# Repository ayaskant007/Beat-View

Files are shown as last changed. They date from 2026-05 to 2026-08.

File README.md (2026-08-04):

# BEAT VIEW SPOTIFY DISPLAY

My very own desktop Spotify display + controller powered by a C3 MINI ESP32 and a ST77XX TFT LCD screen it has 3 mechanical switches to let me control the music playback directly
from my desk without constantly switching windows in my computer.

## Why This Project Was Made

I made this to solve the annyoance of always having to switch tabs/windows and interrupting my work just to skip a song or pause it, so i was just randomly one day decided to look into the stasis starter projects and i seemed to love the idea to built something to fix it so i made it.

## Project Media

[Click this to see the demo video](https://drive.google.com/file/d/1Z7YIdjlfjScMlj2ab83R-hnQqPh4U6T6/view?usp=sharing)





### 3D Model Render
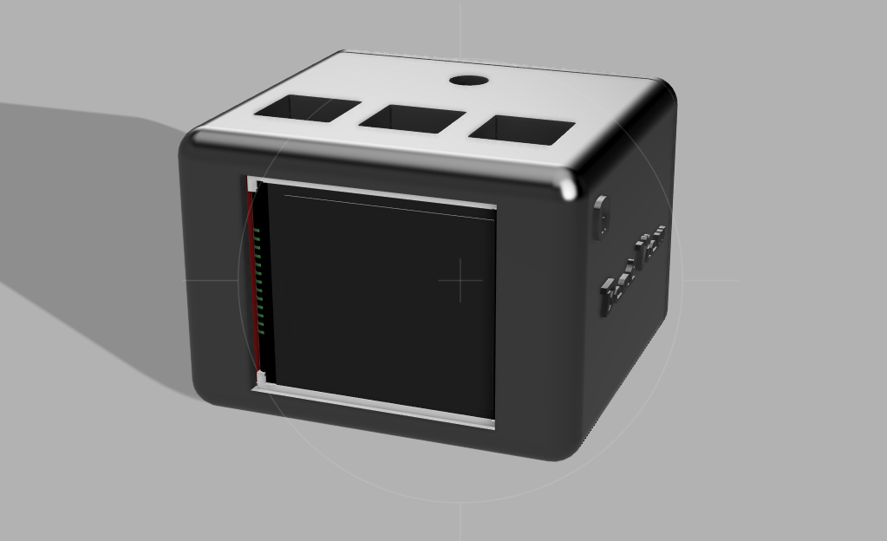
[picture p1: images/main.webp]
Fusion 360 3D Case Model



### PCB Layout
*Everything is handwired and doesnt use a PCB*

### Wiring Diagram
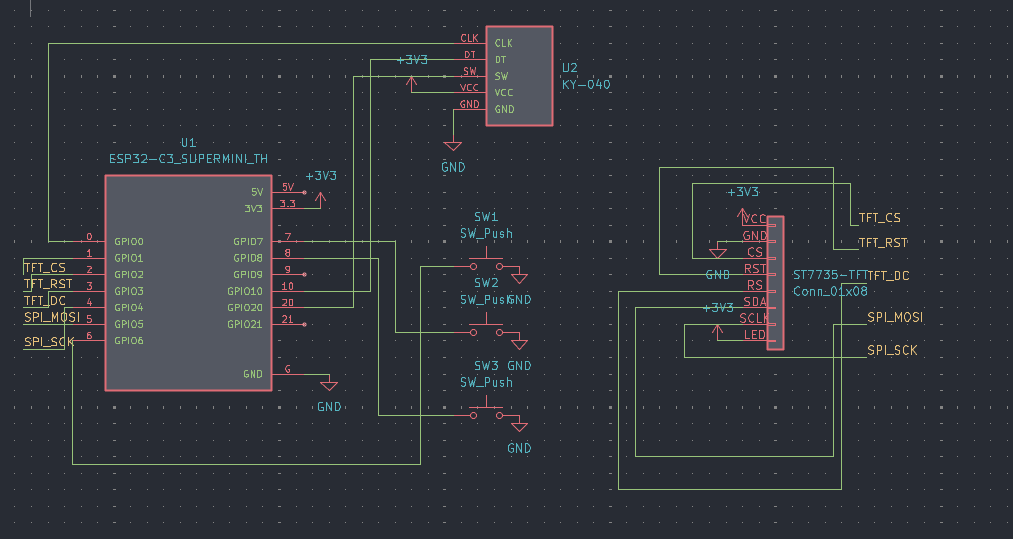
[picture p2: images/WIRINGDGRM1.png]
ESP32 C3 Mini to ST7735R Wiring Diagram


#### Reference Pin Map

| Physical Component | Component Pin Label | Wire to ESP32-C3 Mini Pin |
| --- | --- | --- |
| **1.8" TFT (ST7735R)** | **VCC** | **`3.3V`** |
|  | **GND** | **`GND`** |
|  | **CS** | **`2`** |
|  | **RESET / RST** | **`1`** |
|  | **DC / RS** | **`3`** |
|  | **SDA / MOSI** | **`6`** |
|  | **SCL / SCK** | **`4`** |
|  | **LED / BL** | **`3.3V`** |
| **HMX Xinhai Switches** | **Prev Switch Pin 1** | **`5`** | 
| *(Orientation doesn't* | **Play Switch Pin 1** | **`7`** | 
| *matter for switches)* | **Next Switch Pin 1** | **`TX` (GPIO 21)** | 
|  | **ALL Switch Pin 2s** | **`GND`** | 
| **Rotary Encoder** | **CLK (or A)** | **`0`** | 
|  | **DT (or B)** | **`10`** |  |
|  | **SW (Button Pin 1)** | **`RX` (GPIO 20)** | 
|  | **GND & Button Pin 2** | **`GND`** | 

---

## Bill of Materials (BOM)

| Name | Purpose | Qty | Total (USD) | Distributor | Link |
| :--- | :--- | :---: | :---: | :--- | :--- |
| **Rotary encoder module** | For volume control | 1 | $0.45 | Robocraze | https://robocraze.com/products/rotary-encoder-module?variant=40193048543385 |
| **Breadboard jumper wires** | For connecting the pin headers of the esp to the display and the key switches | 1 | $1.33 | Robocraze | [https://robocraze.com](https://robocraze.com/products/jumper-wire-set-m2m-m2f-f2f-40-pcs-each?variant=40192573636761) |
| **USB C data cable** | For connecting the display to my pc | 1 | $0.71 | Robocraze | [https://robocraze.com](https://robocraze.com/products/type-c-usb-cable-1-metre?variant=40193636303001) |
| **Keycaps** | For the keys for playing, pausing etc etc. | 1 | $1.04 | Meckeys | [https://meckeys.com](https://meckeys.com/shop/accessories/keyboard-accessories/keycaps/blank-dsa-keycaps-1u/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) |
| **Key switches** | For adding the play, pause functionality (HMX Xinhai 63.5g) | 1 | $3.38 | Meckeys | [https://meckeys.com](https://meckeys.com/shop/accessories/keyboard-accessories/keycaps/blank-dsa-keycaps-1u/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) |
| **1.8 inch TFT LCD module** | The display for actually showing the now playing status | 1 | $2.92 | Robocraze | [https://robocraze.com](https://robocraze.com/products/1-8-inch-tft-lcd-module) |
| **ESP32-C3 mini development board - unsoldered** | Main board for actually making the display work by fetching the data from spotify and also controlling what the display shows. | 1 | $2.65 | Robocraze | https://robocraze.com/products/esp32-c3-mini-development-board-unsoldered?variant=48465411506400 |
| **Sandpaper** | For sanding and smoothing the case for better adhesion. | 1 | $0 | Amazon | - |

---

### Additional Costs Summary

* **Tax (USD):** $1.37
* **Shipping (USD):** $1.56
* **Grand Total (USD):** $16.04

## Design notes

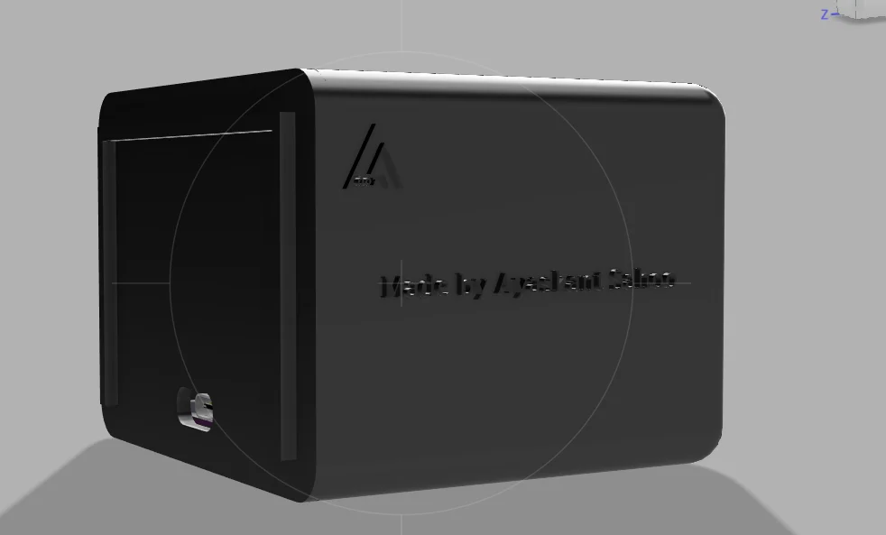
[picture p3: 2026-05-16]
images/1776142731075-7xjrsu.webp

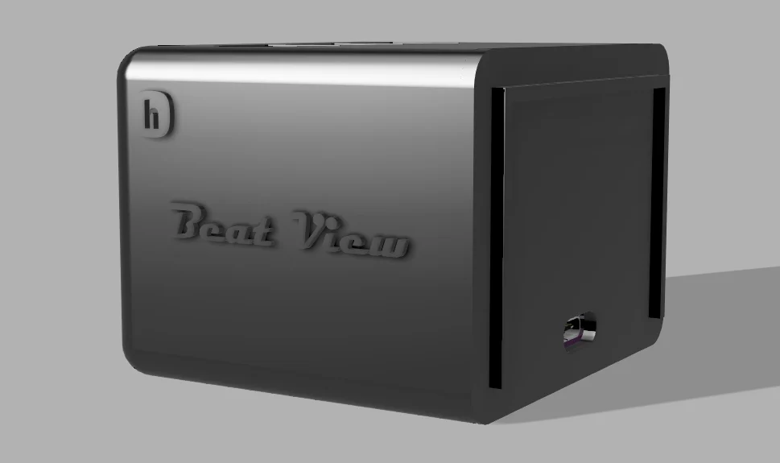
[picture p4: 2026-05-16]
images/1776142708711-ibmdzl.png

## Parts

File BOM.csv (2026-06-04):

Name | Purpose | Quantity | Total Cost (USD) | Link | Distributor
SANDPAPER | FOR SANDING AND SMOOTHING THE CASE FOR BETTER ADHESION | 1 | 0 | https://www.amazon.in/Premium-Automotive-Woodworking-Furniture-Finishing/dp/B0CCW36FQ1 | Amazon
Rotary Encoder Module | FOR VOLUME CONTROL | 1 | 0.45 | https://robocraze.com/products/rotary-encoder-module?variant=40193048543385 | ROBOCRAZE
Breadboard Jumper Wires | For connecting the pin headers of the ESP to the display and the key switches | 1 | 1.33 | https://robocraze.com/products/jumper-wire-set-m2m-m2f-f2f-40-pcs-each?variant=40192573636761 | ROBOCRAZE
USB C data cable | For connecting the display to my pc | 1 | 0.71 | https://robocraze.com/products/type-c-usb-cable-1-metre?variant=40193636303001 | Robocraze
Keycaps | For the keys for playing, pausing etc etc. | 1 | 1.04 | https://meckeys.com/shop/accessories/keyboard-accessories/keycaps/blank-dsa-keycaps-1u/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 | MECKEYS
Key Switches | For adding the play, pause functionality | 1 | 3.38 | https://meckeys.com/shop/accessories/keyboard-accessories/keycaps/blank-dsa-keycaps-1u/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 | MECKEYS
1.8 inch TFT LCD Module | The Display for actually showing the now playing status | 1 | 2.92 | https://robocraze.com/products/1-8-inch-tft-lcd-module | Robocraze
ESP32-C3 Mini Development Board - Unsoldered | Main board for actually making the display work by fetching the data from spotify and also controlling what the display shows. | 1 | 2.65 | https://robocraze.com/products/esp32-c3-mini-development-board-unsoldered?variant=48465411506400 | Robocraze
Tax (USD) |  |  | 1.37
Shipping (USD) |  |  | 1.56
 |  |  | 16.04

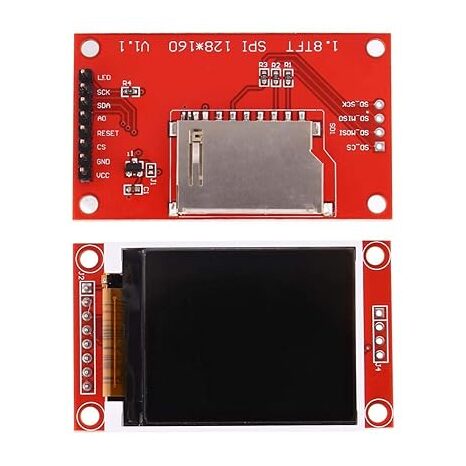
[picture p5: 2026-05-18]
Components/61HpxuwdU3L._SX466_-rotated.jpg

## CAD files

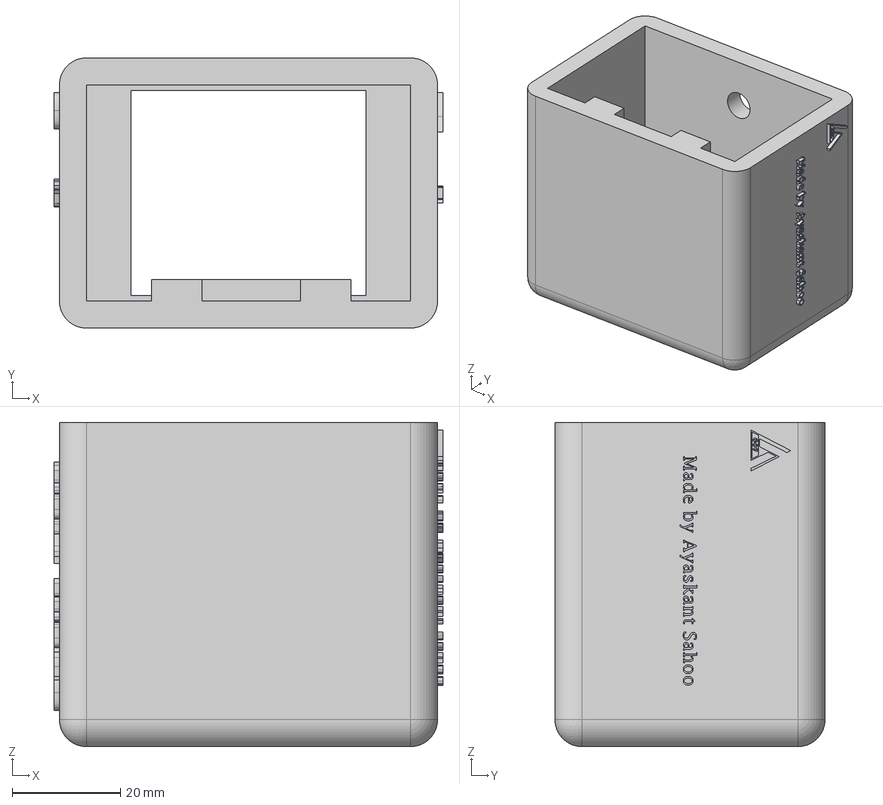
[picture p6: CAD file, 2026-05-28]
production/MainBody.step
72.0 x 50.0 x 60.0 mm

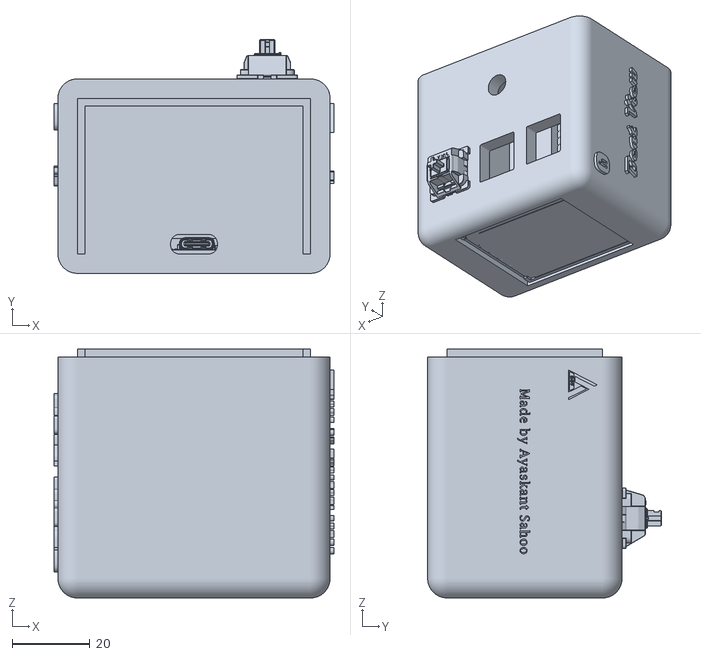
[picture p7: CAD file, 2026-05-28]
CAD/Beat View.stl
72.0 x 60.1 x 64.0

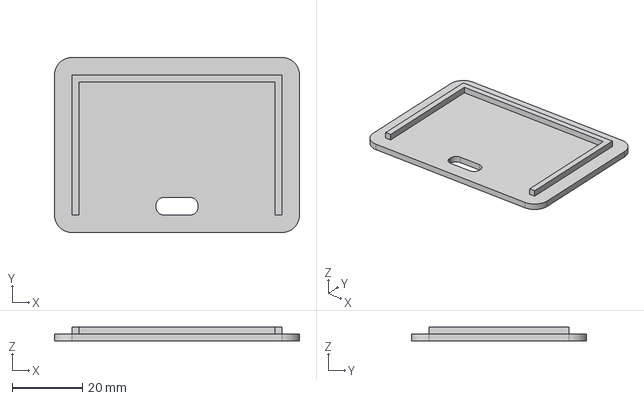
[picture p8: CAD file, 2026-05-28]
production/BackCover.step
70.0 x 50.0 x 4.00 mm

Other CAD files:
CAD/Beat View.f3z
production/BackCover.stl
production/MainBody.stl

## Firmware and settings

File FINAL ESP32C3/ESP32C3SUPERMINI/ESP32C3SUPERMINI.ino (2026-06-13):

#include <Arduino.h>
#include <Adafruit_GFX.h>
#include <Adafruit_ST7735.h>
#include <SPI.h>
#include <math.h>

// =====================================================
// ESP32-C3 SuperMini + ST7735 Media Controller
// Layout: 160x128 landscape
// =====================================================

// ------------------ TFT pins ------------------
#define TFT_CS    2
#define TFT_RST   1
#define TFT_DC    3
#define TFT_SCLK  4
#define TFT_MOSI  6

// ------------------ Controls ------------------
#define BTN_PREV  5
#define BTN_PLAY  7
#define BTN_NEXT  21
#define ENC_CLK   0
#define ENC_DT    10
#define ENC_SW    20

// ------------------ Display geometry ------------------
#define SW          160
#define SH          128

// Layout regions
#define HDR_H       12          // app name strip
#define FTR_H       20          // playback controls
#define BODY_Y      HDR_H
#define FTR_Y       (SH - FTR_H)
#define BODY_H      (FTR_Y - BODY_Y)   // 96px
// Title sub-canvas for proper clipping
#define TITLE_CV_W  (SW - TXT_X - 4)   // 84px wide
#define TITLE_CV_H  16

// Album art
#define ART_SIZE    60
#define ART_X       6
#define ART_Y       (BODY_Y + 4)

// Text area (right of album)
#define TXT_X       72
#define TXT_W       (SW - TXT_X - 4)
#define TITLE_Y     (BODY_Y + 6)
#define TITLE_H     14
#define ARTIST_Y    (BODY_Y + 24)
#define ARTIST_H    10
#define EQ_Y        (BODY_Y + 38)
#define EQ_H        18

// Progress bar (full width below album)
#define PROG_Y      (BODY_Y + 76)
#define PROG_TIME_Y (BODY_Y + 84)

// ------------------ Timing ------------------
#define D_BTN       45
#define D_CLK       3
#define D_SW        300
#define T_UI        40
#define T_VOL       1800
#define T_SCROLL    50
#define SCROLL_GAP  30
#define SCROLL_PAUSE 1000

// ------------------ Colors (RGB565) ------------------
#define C_BG        0x0000
#define C_PANEL     0x18E3
#define C_PANEL_2   0x2965
#define C_TEXT      0xFFFF
#define C_MUTED     0xACD3
#define C_DIM       0x6B4D
#define C_ACCENT    0x07FF
#define C_DANGER    0xF800

Adafruit_ST7735 tft(TFT_CS, TFT_DC, TFT_RST);
GFXcanvas16 bodyCanvas(SW, BODY_H);
GFXcanvas16 footerCanvas(SW, FTR_H);
GFXcanvas16 headerCanvas(SW, HDR_H);
GFXcanvas16 titleCanvas(TITLE_CV_W, TITLE_CV_H);

// ------------------ State ------------------
struct Track {
  String artist = "";
  String name = "";
  String app = "";
  bool playing = false;
  int progress = 0;
  int duration = 0;
};

Track cur;
int vol = 50;
bool shuf = false;
bool muted = false;

// Inputs
int lastClk = HIGH;
bool lastSw = HIGH;
bool lastBtnState[3] = {HIGH, HIGH, HIGH};
unsigned long tBtn[3] = {0, 0, 0};
unsigned long tClk = 0;
unsigned long tSw = 0;
unsigned long tUi = 0;
unsigned long tScroll = 0;
unsigned long tVol = 0;
unsigned long tScrollPause = 0;

bool volVisible = false;
bool scrolling = false;
int scrollX = 0;
int textW = 0;
uint32_t frameId = 0;

// EQ bars (8 bars)
#define EQ_BARS 8
float eqH[EQ_BARS]      = {3, 6, 9, 4, 7, 5, 8, 3};
float targetEq[EQ_BARS] = {3, 6, 9, 4, 7, 5, 8, 3};

String rxLine;

// Album art
uint16_t albumArt[ART_SIZE * ART_SIZE];
bool artReady = false;
bool artReceiving = false;
bool artAwaitTerm = false;
int artExpected = 0;
int artIndex = 0;
int artW = ART_SIZE;
int artH = ART_SIZE;

// Theme color from PC (extracted from album art)
uint16_t themeColor = C_ACCENT;
uint8_t themeR = 0, themeG = 200, themeB = 255;

// Visual pulse for play indicator
float pulsePhase = 0;

// ------------------ Helpers ------------------
static bool valid(const String& s) {
  return s.length() > 0 && s != "null" && s != "error";
}

static String safeText(String s, int maxLen = 60) {
  s.replace("\r", " ");
  s.replace("\n", " ");
  s.replace("|", "/");
  s.trim();
  if ((int)s.length() > maxLen) s = s.substring(0, maxLen);
  return s;
}

static String formatTime(int ms) {
  if (ms < 0) ms = 0;
  int total = ms / 1000;
  int m = total / 60;
  int s = total % 60;
  char buf[10];
  snprintf(buf, sizeof(buf), "%d:%02d", m, s);
  return String(buf);
}

static uint16_t rgb565(uint8_t r, uint8_t g, uint8_t b) {
  return ((r & 0xF8) << 8) | ((g & 0xFC) << 3) | (b >> 3);
}

static uint16_t blend565(uint16_t a, uint16_t b, uint8_t t) {
  uint8_t ar = (a >> 11) & 0x1F, ag = (a >> 5) & 0x3F, ab = a & 0x1F;
  uint8_t br = (b >> 11) & 0x1F, bg = (b >> 5) & 0x3F, bb = b & 0x1F;
  uint8_t rr = ar + (((int)br - ar) * t >> 8);
  uint8_t gg = ag + (((int)bg - ag) * t >> 8);
  uint8_t bb2 = ab + (((int)bb - ab) * t >> 8);
  return (rr << 11) | (gg << 5) | bb2;
}

static uint16_t darken(uint16_t c, uint8_t amt) {
  return blend565(c, C_BG, amt);
}

static uint16_t lighten(uint16_t c, uint8_t amt) {
  return blend565(c, C_TEXT, amt);
}

static String initialsFromTitle(const String& s) {
  String out;
  bool take = true;
  for (unsigned i = 0; i < s.length() && out.length() < 2; i++) {
    char c = s[i];
    if (isalnum((unsigned char)c)) {
      if (take) { out += (char)toupper(c); take = false; }
    } else take = true;
  }
  if (out.length() == 0) out = "?";
  return out;
}

// ------------------ Drawing primitives ------------------

// Vertical gradient fill on canvas
static void fillGradV(GFXcanvas16& c, int x, int y, int w, int h, uint16_t top, uint16_t bot) {
  for (int i = 0; i < h; i++) {
    uint8_t t = (h > 1) ? (uint8_t)((i * 255L) / (h - 1)) : 0;
    c.drawFastHLine(x, y + i, w, blend565(top, bot, t));
  }
}

// Draw album art with rounded corners and subtle border
static void drawAlbumArt(GFXcanvas16& c) {
  int ay = ART_Y - BODY_Y;  // translate to canvas-local Y
  
  if (artReady && artW == ART_SIZE && artH == ART_SIZE) {
    c.drawRGBBitmap(ART_X, ay, albumArt, ART_SIZE, ART_SIZE);
  } else {
    // Fallback: gradient square with initials
    uint16_t topC = lighten(themeColor, 40);
    uint16_t botC = darken(themeColor, 60);
    fillGradV(c, ART_X, ay, ART_SIZE, ART_SIZE, topC, botC);
    
    // Decorative circle
    c.drawCircle(ART_X + ART_SIZE/2, ay + ART_SIZE/2, 18, lighten(themeColor, 80));
    c.drawCircle(ART_X + ART_SIZE/2, ay + ART_SIZE/2, 14, lighten(themeColor, 120));
    
    String init = initialsFromTitle(valid(cur.name) ? cur.name : "?");
    c.setTextSize(3);
    c.setTextColor(C_TEXT);
    int16_t x1, y1; uint16_t tw, th;
    c.getTextBounds(init, 0, 0, &x1, &y1, &tw, &th);
    c.setCursor(ART_X + (ART_SIZE - tw)/2, ay + (ART_SIZE - th)/2);
    c.print(init);
  }
  
  // Border
  c.drawRect(ART_X - 1, ay - 1, ART_SIZE + 2, ART_SIZE + 2, darken(themeColor, 100));
  c.drawRect(ART_X, ay, ART_SIZE, ART_SIZE, themeColor);
}

// Animated EQ bars
static void drawEqBars(GFXcanvas16& c) {
  int ey = EQ_Y - BODY_Y;
  int barW = 3;
  int gap = 2;
  int totalW = EQ_BARS * (barW + gap) - gap;
  int startX = TXT_X;
  
  for (int i = 0; i < EQ_BARS; i++) {
    int bx = startX + i * (barW + gap);
    
    // Background slot
    c.fillRect(bx, ey, barW, EQ_H, C_PANEL);
    
    if (cur.playing) {
      // Animate toward target
      if (abs(eqH[i] - targetEq[i]) < 0.5f) {
        targetEq[i] = random(2, EQ_H + 1);
      }
      eqH[i] += (targetEq[i] - eqH[i]) * 0.35f;
      
      int h = (int)eqH[i];
      if (h < 2) h = 2;
      
      // Gradient bar
      for (int j = 0; j < h; j++) {
        uint8_t t = (uint8_t)((j * 255L) / EQ_H);
        uint16_t col = blend565(themeColor, lighten(themeColor, 120), t);
        c.drawFastHLine(bx, ey + EQ_H - h + j, barW, col);
      }
    } else {
      // Paused: flat low bar
      eqH[i] = 2;
      c.fillRect(bx, ey + EQ_H - 2, barW, 2, C_DIM);
    }
  }
}

// Progress bar
static void drawProgress(GFXcanvas16& c) {
  int py = PROG_Y - BODY_Y;
  int pad = 6;
  int barW = SW - pad * 2;
  int barH = 4;
  
  // Background track
  c.fillRoundRect(pad, py, barW, barH, 2, C_PANEL);
  
  int pct = (cur.duration > 0) ? 
            map(constrain(cur.progress, 0, cur.duration), 0, cur.duration, 0, barW) : 0;
  
  if (pct > 0) {
    // Gradient fill
    for (int i = 0; i < pct; i++) {
      uint8_t t = (uint8_t)((i * 255L) / barW);
      uint16_t col = blend565(darken(themeColor, 40), lighten(themeColor, 60), t);
      c.drawFastVLine(pad + i, py, barH, col);
    }
    // Playhead dot
    int dotX = pad + pct;
    if (dotX < pad + barW) {
      c.fillCircle(dotX, py + barH/2, 3, C_TEXT);
      c.drawCircle(dotX, py + barH/2, 3, themeColor);
    }
  }
  
  // Time labels
  int ty = PROG_TIME_Y - BODY_Y;
  c.setTextSize(1);
  c.setTextColor(C_MUTED);
  c.setCursor(pad, ty);
  c.print(formatTime(cur.progress));
  
  String rt = formatTime(cur.duration);
  int16_t x1, y1; uint16_t tw, th;
  c.getTextBounds(rt, 0, 0, &x1, &y1, &tw, &th);
  c.setCursor(SW - pad - tw, ty);
  c.print(rt);
}

// Scrolling title text
static void drawTitle(GFXcanvas16& c) {
  String title = valid(cur.name) ? cur.name : "No track playing";
  title = safeText(title, 80);
  
  // Render onto title sub-canvas (hard-clipped region)
  titleCanvas.fillScreen(C_BG);
  // Match body gradient at title row so it blends
  uint16_t bgTop = darken(themeColor, 220);
  uint16_t bgBot = C_BG;
  int rowY = TITLE_Y - BODY_Y;
  for (int i = 0; i < TITLE_CV_H; i++) {
    int absY = rowY + i;
    uint8_t t = (BODY_H > 1) ? (uint8_t)((absY * 255L) / (BODY_H - 1)) : 0;
    titleCanvas.drawFastHLine(0, i, TITLE_CV_W, blend565(bgTop, bgBot, t));
  }
  
  titleCanvas.setTextSize(2);
  titleCanvas.setTextColor(C_TEXT);
  titleCanvas.setTextWrap(false);
  
  int16_t x1, y1; uint16_t tw, th;
  titleCanvas.getTextBounds(title, 0, 0, &x1, &y1, &tw, &th);
  textW = tw;
  
  if (textW > TITLE_CV_W) {
    scrolling = true;
    titleCanvas.setCursor(scrollX, 1);
    titleCanvas.print(title);
    
    int secondX = scrollX + textW + SCROLL_GAP;
    if (secondX < TITLE_CV_W) {
      titleCanvas.setCursor(secondX, 1);
      titleCanvas.print(title);
    }
  } else {
    scrolling = false;
    scrollX = 0;
    titleCanvas.setCursor(0, 1);
    titleCanvas.print(title);
  }
  
  // Blit title canvas onto body canvas - pixels outside TITLE_CV_W are physically gone
  c.drawRGBBitmap(TXT_X, rowY, titleCanvas.getBuffer(), TITLE_CV_W, TITLE_CV_H);
}

// Artist line
static void drawArtist(GFXcanvas16& c) {
  String artist = valid(cur.artist) ? cur.artist : "Open music on Windows";
  artist = safeText(artist, 30);
  
  c.setTextSize(1);
  c.setTextColor(lighten(themeColor, 80));
  
  // Truncate with ellipsis if too long
  int16_t x1, y1; uint16_t tw, th;
  c.getTextBounds(artist, 0, 0, &x1, &y1, &tw, &th);
  while ((int)tw > TXT_W && artist.length() > 4) {
    artist = artist.substring(0, artist.length() - 2);
    c.getTextBounds(artist + "..", 0, 0, &x1, &y1, &tw, &th);
  }
  if (tw > TXT_W - 12) artist = artist.substring(0, artist.length() - 2) + "..";
  
  c.setCursor(TXT_X, ARTIST_Y - BODY_Y);
  c.print(artist);
}

// Volume popup overlay
static void drawVolumePopup(GFXcanvas16& c) {
  int pw = 130;
  int ph = 32;
  int px = (SW - pw) / 2;
  int py = (BODY_H - ph) / 2;
  
  // Shadow
  c.fillRoundRect(px + 2, py + 2, pw, ph, 6, C_BG);
  // Panel
  c.fillRoundRect(px, py, pw, ph, 6, C_PANEL_2);
  c.drawRoundRect(px, py, pw, ph, 6, themeColor);
  
  // Speaker icon (simple)
  int ix = px + 8;
  int iy = py + ph/2;
  c.fillTriangle(ix, iy - 4, ix + 6, iy - 6, ix + 6, iy + 6, C_TEXT);
  c.fillTriangle(ix, iy + 4, ix + 6, iy + 6, ix + 6, iy - 6, C_TEXT);
  if (vol > 30 && !muted) c.drawCircle(ix + 10, iy, 4, C_TEXT);
  if (vol > 70 && !muted) c.drawCircle(ix + 10, iy, 7, C_TEXT);
  if (muted) {
    c.drawLine(ix, iy - 6, ix + 14, iy + 6, C_DANGER);
    c.drawLine(ix, iy + 6, ix + 14, iy - 6, C_DANGER);
  }
  
  // Bar
  int barX = px + 28;
  int barY = py + ph/2 - 3;
  int barW = pw - 60;
  c.fillRoundRect(barX, barY, barW, 6, 3, C_BG);
  int fill = map(constrain(vol, 0, 100), 0, 100, 0, barW);
  if (fill > 0) {
    for (int i = 0; i < fill; i++) {
      uint8_t t = (uint8_t)((i * 255L) / barW);
      c.drawFastVLine(barX + i, barY, 6, blend565(themeColor, lighten(themeColor, 100), t));
    }
  }
  
  // Percent
  c.setTextSize(1);
  c.setTextColor(C_TEXT);
  char buf[8];
  snprintf(buf, sizeof(buf), "%d%%", vol);
  int16_t x1, y1; uint16_t tw, th;
  c.getTextBounds(buf, 0, 0, &x1, &y1, &tw, &th);
  c.setCursor(px + pw - tw - 8, py + ph/2 - 3);
  c.print(buf);
}

// ------------------ Region draw functions ------------------

static void drawHeader() {
  headerCanvas.fillScreen(C_BG);
  fillGradV(headerCanvas, 0, 0, SW, HDR_H, darken(themeColor, 180), C_BG);
  
  headerCanvas.setTextSize(1);
  headerCanvas.setTextColor(lighten(themeColor, 60));
  headerCanvas.setCursor(4, 2);
  headerCanvas.print("NOW PLAYING");
  
  // App badge on right
  String app = valid(cur.app) ? safeText(cur.app, 12) : String("---");
  app.toUpperCase();
  int16_t x1, y1; uint16_t tw, th;
  headerCanvas.getTextBounds(app, 0, 0, &x1, &y1, &tw, &th);
  headerCanvas.setTextColor(C_MUTED);
  headerCanvas.setCursor(SW - tw - 4, 2);
  headerCanvas.print(app);
  
  // Status dot
  uint16_t dotC = valid(cur.name) ? (cur.playing ? themeColor : C_DIM) : C_DANGER;
  headerCanvas.fillCircle(SW - tw - 12, 5, 2, dotC);
  
  tft.drawRGBBitmap(0, 0, headerCanvas.getBuffer(), SW, HDR_H);
}

static void drawBody() {
  // Background gradient using theme color
  uint16_t bgTop = darken(themeColor, 220);
  uint16_t bgBot = C_BG;
  fillGradV(bodyCanvas, 0, 0, SW, BODY_H, bgTop, bgBot);
  
  drawAlbumArt(bodyCanvas);
  drawTitle(bodyCanvas);
  drawArtist(bodyCanvas);
  drawEqBars(bodyCanvas);
  drawProgress(bodyCanvas);
  
  if (volVisible) {
    drawVolumePopup(bodyCanvas);
  }
  
  tft.drawRGBBitmap(0, BODY_Y, bodyCanvas.getBuffer(), SW, BODY_H);
}

static void drawFooter() {
  footerCanvas.fillScreen(C_BG);
  fillGradV(footerCanvas, 0, 0, SW, FTR_H, C_BG, darken(themeColor, 200));
  
  // Top separator
  footerCanvas.drawFastHLine(0, 0, SW, darken(themeColor, 100));
  
  int cy = FTR_H / 2;
  
  // Prev button
  int px1 = 28;
  footerCanvas.fillCircle(px1, cy, 8, C_PANEL);
  // Draw prev triangle
  footerCanvas.fillTriangle(px1 + 2, cy - 4, px1 + 2, cy + 4, px1 - 3, cy, C_TEXT);
  footerCanvas.fillRect(px1 - 4, cy - 4, 2, 9, C_TEXT);
  
  // Play/Pause button (center, bigger)
  int px2 = SW / 2;
  pulsePhase += 0.15f;
  int pulse = cur.playing ? (int)(sin(pulsePhase) * 1.5f + 0.5f) : 0;
  footerCanvas.fillCircle(px2, cy, 10 + pulse, cur.playing ? themeColor : C_PANEL_2);
  footerCanvas.drawCircle(px2, cy, 10 + pulse, lighten(themeColor, 80));
  
  if (cur.playing) {
    // Pause icon
    footerCanvas.fillRect(px2 - 4, cy - 5, 3, 10, C_TEXT);
    footerCanvas.fillRect(px2 + 1, cy - 5, 3, 10, C_TEXT);
  } else {
    // Play icon
    footerCanvas.fillTriangle(px2 - 3, cy - 5, px2 - 3, cy + 5, px2 + 4, cy, C_TEXT);
  }
  
  // Next button
  int px3 = SW - 28;
  footerCanvas.fillCircle(px3, cy, 8, C_PANEL);
  footerCanvas.fillTriangle(px3 - 2, cy - 4, px3 - 2, cy + 4, px3 + 3, cy, C_TEXT);
  footerCanvas.fillRect(px3 + 2, cy - 4, 2, 9, C_TEXT);
  
  // Shuffle indicator (small, top-right of footer)
  if (shuf) {
    footerCanvas.fillRoundRect(SW - 18, 2, 16, 6, 2, themeColor);
    footerCanvas.setTextSize(1);
    footerCanvas.setTextColor(C_BG);
    footerCanvas.setCursor(SW - 16, 2);
    footerCanvas.print("SHF");
  }
  
  tft.drawRGBBitmap(0, FTR_Y, footerCanvas.getBuffer(), SW, FTR_H);
}

// ------------------ Serial protocol ------------------

static void parseTrackLine(const String& line) {
  // TRACK|artist|title|playing|pos|dur|vol|app|r|g|b
  int idx[11];
  int found = 0;
  idx[0] = -1;
  for (int i = 0; i < (int)line.length() && found < 10; i++) {
    if (line[i] == '|') idx[++found] = i;
  }
  if (found < 10) return;
  
  auto field = [&](int n) -> String {
    int start = idx[n] + 1;
    int end = (n + 1 <= 10) ? idx[n + 1] : line.length();
    return line.substring(start, end);
  };
  
  String artist = safeText(field(1), 60);
  String title  = safeText(field(2), 80);
  bool playing  = field(3).toInt() == 1;
  int pos       = field(4).toInt();
  int dur       = field(5).toInt();
  int newVol    = field(6).toInt();
  String app    = safeText(field(7), 20);
  int r = field(8).toInt();
  int g = field(9).toInt();
  int b = field(10).toInt();
  
  if (pos < 0) pos = 0;
  if (dur < 0) dur = 0;
  if (dur > 0 && pos > dur) pos = dur;
  
  bool themeChanged = false;
  if (r >= 0 && g >= 0 && b >= 0) {
    uint16_t nt = rgb565(r, g, b);
    if (nt != themeColor) {
      themeColor = nt;
      themeR = r; themeG = g; themeB = b;
      themeChanged = true;
    }
  }
  
  bool metaChanged = (title != cur.name) || (artist != cur.artist) || (app != cur.app);
  
  cur.name = title;
  cur.artist = artist;
  cur.playing = playing;
  cur.progress = pos;
  cur.duration = dur;
  cur.app = app;
  if (newVol >= 0) vol = constrain(newVol, 0, 100);
  
  if (metaChanged) {
    scrollX = 0;
    tScrollPause = millis();
  }
  
  if (metaChanged || themeChanged) {
    drawHeader();
  }
}

static void beginAlbumPacket(int w, int h, int len) {
  artReceiving = true;
  artAwaitTerm = false;
  artExpected = len;
  artIndex = 0;
  artW = w;
  artH = h;
  if (w == 0 || h == 0 || len == 0) {
    artReady = false;
    artReceiving = false;
    artAwaitTerm = false;
  }
}

static void handleSerialByte(uint8_t c) {
  if (artReceiving) {
    if (artIndex < artExpected) {
      int pixIdx = artIndex / 2;
      if (pixIdx < ART_SIZE * ART_SIZE) {
        if ((artIndex & 1) == 0) {
          albumArt[pixIdx] = ((uint16_t)c) << 8;
        } else {
          albumArt[pixIdx] |= c;
        }
      }
      artIndex++;
      if (artIndex >= artExpected) {
        artReceiving = false;
        artAwaitTerm = true;
        artReady = (artW == ART_SIZE && artH == ART_SIZE);
      }
    }
    return;
  }
  if (artAwaitTerm) {
    if (c == '\n') artAwaitTerm = false;
    return;
  }
  
  if (c == '\n') {
    rxLine.trim();
    if (rxLine.startsWith("TRACK|")) {
      parseTrackLine(rxLine);
    } else if (rxLine.startsWith("ART|")) {
      int p1 = rxLine.indexOf('|');
      int p2 = rxLine.indexOf('|', p1 + 1);
      int p3 = rxLine.indexOf('|', p2 + 1);
      if (p1 > 0 && p2 > 0 && p3 > 0) {
        int w = rxLine.substring(p1 + 1, p2).toInt();
        int h = rxLine.substring(p2 + 1, p3).toInt();
        int len = rxLine.substring(p3 + 1).toInt();
        if (len == 0) {
          artReady = false;
        } else if (w == ART_SIZE && h == ART_SIZE && len <= (int)sizeof(albumArt)) {
          beginAlbumPacket(w, h, len);
        }
      }
    } else if (rxLine.startsWith("VOL|")) {
      vol = constrain(rxLine.substring(4).toInt(), 0, 100);
      volVisible = true;
      tVol = millis();
    }
    rxLine = "";
  } else if (c != '\r') {
    rxLine += (char)c;
    if (rxLine.length() > 250) rxLine = "";
  }
}

// ------------------ Inputs ------------------

static void sendCommand(const String& cmd) {
  Serial.println(cmd);
}

void handleButtons() {
  unsigned long t = millis();
  
  bool curPlay = digitalRead(BTN_PLAY);
  if (curPlay == LOW && lastBtnState[0] == HIGH && t - tBtn[0] > D_BTN) {
    tBtn[0] = t;
    sendCommand("BTN:TOGGLE");
    cur.playing = !cur.playing;
  }
  lastBtnState[0] = curPlay;
  
  bool curNext = digitalRead(BTN_NEXT);
  if (curNext == LOW && lastBtnState[1] == HIGH && t - tBtn[1] > D_BTN) {
    tBtn[1] = t;
    sendCommand("BTN:NEXT");
  }
  lastBtnState[1] = curNext;
  
  bool curPrev = digitalRead(BTN_PREV);
  if (curPrev == LOW && lastBtnState[2] == HIGH && t - tBtn[2] > D_BTN) {
    tBtn[2] = t;
    sendCommand("BTN:PREV");
  }
  lastBtnState[2] = curPrev;
}

void handleEncoder() {
  unsigned long t = millis();
  int clk = digitalRead(ENC_CLK);
  bool sw = digitalRead(ENC_SW);
  
  if (clk != lastClk && clk == LOW && t - tClk > D_CLK) {
    tClk = t;
    int delta = (digitalRead(ENC_DT) != clk) ? -4 : 4;
    vol = constrain(vol + delta, 0, 100);
    sendCommand(String("BTN:VOL:") + String(vol));
    volVisible = true;
    tVol = t;
  }
  lastClk = clk;
  
  if (lastSw == HIGH && !sw && t - tSw > D_SW) {
    tSw = t;
    muted = !muted;
    sendCommand(muted ? "BTN:MUTE" : "BTN:UNMUTE");
    volVisible = true;
    tVol = t;
  }
  lastSw = sw;
  
  if (volVisible && (t - tVol >= T_VOL)) {
    volVisible = false;
  }
}

// ------------------ Setup / Loop ------------------
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
void loop() {
  if (artReceiving) {
    int avail = Serial.available();
    if (avail > 0) {
      int toRead = min(avail, artExpected - artIndex);
      if (toRead > 0) {
        uint8_t tempBuf[64];
        int chunk = min(toRead, 64);
        int readBytes = Serial.readBytes(tempBuf, chunk);
        for (int i = 0; i < readBytes; i++) {
          int pixIdx = artIndex / 2;
          if (pixIdx < ART_SIZE * ART_SIZE) {
            if ((artIndex & 1) == 0) {
              albumArt[pixIdx] = ((uint16_t)tempBuf[i]) << 8;
            } else {
              albumArt[pixIdx] |= tempBuf[i];
            }
          }
          artIndex++;
        }
        if (artIndex >= artExpected) {
          artReceiving = false;
          artAwaitTerm = true;
          artReady = (artW == ART_SIZE && artH == ART_SIZE);
        }
      }
    }
  } else {
    while (Serial.available()) {
      handleSerialByte((uint8_t)Serial.read());
    }
  }
  
  handleButtons();
  handleEncoder();
  
  unsigned long t = millis();
  
  if (t - tUi >= T_UI) {
    tUi = t;
    frameId++;
    
    // Scroll logic with pause at start
    if (scrolling && !volVisible && !artReceiving && !artAwaitTerm) {
      if (t - tScrollPause > SCROLL_PAUSE && t - tScroll >= T_SCROLL) {
        tScroll = t;
        scrollX -= 1;
        if (scrollX <= -(textW + SCROLL_GAP)) {
          scrollX = 0;
          tScrollPause = t;
        }
      }
    }
    
    if (!artReceiving && !artAwaitTerm) {
      drawBody();
      drawFooter();   // redraw for pulse animation
    }
  }
}

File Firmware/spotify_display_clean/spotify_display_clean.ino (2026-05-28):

#include <Arduino.h>
#include <ArduinoJson.h>
#include <Adafruit_GFX.h>
#include <Adafruit_ST7735.h>
#include <WiFi.h>
#include <SpotifyEsp32.h>
#include <SPI.h>
#include <math.h>

const char* SSID          = "YOUR_WIFI_SSID";
const char* PASSWORD      = "YOUR_WIFI_PASSWORD";
const char* CLIENT_ID     = "YOUR_CLIENT_ID";
const char* CLIENT_SECRET = "YOUR_CLIENT_SECRET";

#define TFT_CS   2
#define TFT_RST  1
#define TFT_DC   3
#define TFT_SCLK 4
#define TFT_MOSI 6

#define BTN_PREV 5
#define BTN_PLAY 7
#define BTN_NEXT 21

#define ENC_CLK  0
#define ENC_DT   10
#define ENC_SW   20

#define C_BG       0x0000
#define C_SURFACE  0x0841
#define C_BORDER   0x2945
#define C_GREEN    0x1DCA
#define C_GREEN_DK 0x0E44
#define C_WHITE    0xFFFF
#define C_MUTED    0x7BEF
#define C_DIM      0x39E7
#define C_RED      0xF800

#define SW        160
#define SH        128

#define HDR_H      20
#define FTR_Y     108
#define TRK_Y      34
#define ART_Y      58
#define BAR_Y      82
#define BAR_H       3
#define TIME_Y     88
#define BAR_PAD    10

#define T_API        2500
#define T_SCROLL       28
#define T_EQ           55
#define T_VOL        1800
#define SCROLL_PAUSE 1200
#define SCROLL_GAP     48
#define D_BTN          50
#define D_CLK           4
#define D_SW          300

const unsigned char icon_play[] PROGMEM = {
    0x00,0x00, 0x03,0x00, 0x07,0x00, 0x0f,0x00, 0x1f,0x00, 0x3f,0x00,
    0x7f,0x00, 0xff,0x00, 0xff,0x00, 0x7f,0x00, 0x3f,0x00, 0x1f,0x00,
    0x0f,0x00, 0x07,0x00, 0x03,0x00, 0x00,0x00
};
const unsigned char icon_pause[] PROGMEM = {
    0x00,0x00, 0x3c,0x3c, 0x3c,0x3c, 0x3c,0x3c, 0x3c,0x3c, 0x3c,0x3c,
    0x3c,0x3c, 0x3c,0x3c, 0x3c,0x3c, 0x3c,0x3c, 0x3c,0x3c, 0x3c,0x3c,
    0x3c,0x3c, 0x3c,0x3c, 0x3c,0x3c, 0x00,0x00
};
const unsigned char icon_next[] PROGMEM = {
    0x00,0x00, 0x0c,0x30, 0x1c,0x30, 0x3c,0x30, 0x7c,0x30, 0xfc,0x30,
    0xfc,0x30, 0xfc,0x30, 0xfc,0x30, 0xfc,0x30, 0xfc,0x30, 0x7c,0x30,
    0x3c,0x30, 0x1c,0x30, 0x0c,0x30, 0x00,0x00
};
const unsigned char icon_prev[] PROGMEM = {
    0x00,0x00, 0x0c,0x30, 0x0c,0x38, 0x0c,0x3c, 0x0c,0x7c, 0x0c,0xfc,
    0x0c,0xfc, 0x0c,0xfc, 0x0c,0xfc, 0x0c,0xfc, 0x0c,0xfc, 0x0c,0x7c,
    0x0c,0x3c, 0x0c,0x38, 0x0c,0x30, 0x00,0x00
};
const unsigned char icon_shuffle[] PROGMEM = {
    0x00,0x00, 0x81,0x81, 0x42,0x42, 0x24,0x24, 0x18,0x18, 0x18,0x18,
    0x24,0x24, 0x42,0x42, 0x42,0x42, 0x24,0x24, 0x18,0x18, 0x18,0x18,
    0x24,0x24, 0x42,0x42, 0x81,0x81, 0x00,0x00
};
const unsigned char icon_speaker[] PROGMEM = {
    0x01,0x80, 0x03,0x80, 0x07,0x00, 0x3f,0x00, 0x3f,0x44, 0x3f,0x88,
    0x3f,0x10, 0x3f,0x10, 0x3f,0x10, 0x3f,0x88, 0x3f,0x44, 0x07,0x00,
    0x03,0x80, 0x01,0x80, 0x00,0x00, 0x00,0x00
};

Adafruit_ST7735 tft(TFT_CS, TFT_DC, TFT_RST);
Spotify         sp(CLIENT_ID, CLIENT_SECRET);

GFXcanvas16 trackCanvas(SW, 20);

struct TrackState {
    String name, artist;
    bool   playing  = false;
    bool   shuffle  = false;
    int    progress = 0;
    int    duration = 0;
};
TrackState cur;

int  vol              = 50;
bool volVisible       = false;
bool pendingVolUpdate = false;

float        scrollX    = 0.0f;
int          textW      = 0;
bool         scrolling  = false;
bool         scrollHeld = true;
unsigned long tScrollHeld = 0;

#define EQ_BARS   7
#define EQ_BAR_W  5
#define EQ_GAP    2
#define EQ_MAX_H  13
#define EQ_BASE_Y (HDR_H - 4)

float        eqPos[EQ_BARS];
float        eqVel[EQ_BARS];
float        eqTgt[EQ_BARS];
unsigned long eqNextTgt[EQ_BARS];

void initEQ() {
    for (int i = 0; i < EQ_BARS; i++) {
        eqPos[i] = 2.0f; eqVel[i] = 0.0f;
        eqTgt[i] = 2.0f; eqNextTgt[i] = 0;
    }
}

unsigned long tApi = 0, tScroll = 0, tEq = 0, tVol = 0, tWifiCheck = 0;
unsigned long tBtn[3] = {0, 0, 0};
unsigned long tClk = 0, tSw = 0, tVolTurn = 0;
bool          lastBtn[3]  = {HIGH, HIGH, HIGH};
int           lastClk     = HIGH;
bool          lastSw      = HIGH;

bool valid(const String& s) {
    return s.length() > 0 && s != "null" &&
           s != "error" && s != "Something went wrong";
}

String fmtTime(int ms) {
    if (ms <= 0) return "0:00";
    int s = ms / 1000;
    char buf[8];
    snprintf(buf, sizeof(buf), "%d:%02d", s / 60, s % 60);
    return String(buf);
}

uint16_t wifiColor() {
    return (WiFi.status() == WL_CONNECTED) ? C_GREEN : C_RED;
}

void wifiKeepAlive() {
    if (WiFi.status() == WL_CONNECTED) return;
    unsigned long t = millis();
    if (t - tWifiCheck >= 10000) {
        tWifiCheck = t;
        WiFi.disconnect();
        WiFi.begin(SSID, PASSWORD);
    }
}

void animBoot() {
    tft.fillScreen(C_BG);


    for (int x = 0; x < SW; x++) {
        int h = 3 + (int)(sin(x * 0.18f) * 11.0f);
        tft.drawFastVLine(x, SH / 2 - h / 2, h, C_GREEN);
        if (x > 6) tft.drawFastVLine(x - 6, SH / 2 - 14, 28, C_BG);
        delay(3);
    }
    tft.fillScreen(C_BG);


    const char* logo  = "SPOTIFY";
    const int   nChar = 7;
    int logoW  = nChar * 12;
    int logoX  = (SW - logoW) / 2;
    int logoY  = SH / 2 - 14;

    tft.setTextSize(2);

    for (int i = 0; i < nChar; i++) {

        for (int dy = -14; dy <= 0; dy += 2) {
            tft.fillRect(logoX + i * 12, logoY - 2, 12, 18, C_BG);
            tft.setCursor(logoX + i * 12, logoY + dy);
            tft.setTextColor(C_GREEN);
            tft.print(logo[i]);
            delay(4);
        }

        tft.fillRect(logoX + i * 12, logoY - 2, 12, 18, C_BG);
        tft.setCursor(logoX + i * 12, logoY);
        tft.setTextColor(C_WHITE);
        tft.print(logo[i]);
        delay(30);
    }


    for (int x = logoX; x < logoX + logoW; x++) {
        tft.drawPixel(x, logoY + 17, C_GREEN);
        delay(2);
    }


    delay(200);
    tft.setTextSize(1);
    tft.setTextColor(C_MUTED);
    int tagW = 9 * 6;
    tft.setCursor((SW - tagW) / 2, logoY + 22);
    tft.print("BEAT VIEW");

    delay(700);


    for (int h = 1; h <= SH / 2 + 4; h += 4) {
        tft.fillRect(0, SH / 2 - h, SW, h * 2, C_BG);
        delay(6);
    }
}

void statusScreen(const char* line1, const char* line2 = nullptr) {
    tft.fillScreen(C_BG);
    tft.setTextSize(1);
    tft.setTextColor(C_MUTED);
    int y = SH / 2 - (line2 ? 8 : 4);
    tft.setCursor((SW - strlen(line1) * 6) / 2, y);
    tft.print(line1);
    if (line2) {
        tft.setTextColor(C_DIM);
        tft.setCursor((SW - strlen(line2) * 6) / 2, y + 12);
        tft.print(line2);
    }
}
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

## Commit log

2026-05-16 Added the files for 3d models and firmware
    [BackCover.step, Beat View.f3z, C3 Mini Board-LP Pins.step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]
2026-05-16 Revise README with project details and BOM
    Updated project title and added detailed project description, media, wiring diagram, and bill of materials.
2026-05-16 Revise Bill of Materials and add cost summary
    Updated the Bill of Materials section to include new components and their details, along with an additional costs summary.
2026-05-17 ADDED FINAL CAD
    [BackCover.step, BackCover.stl, Beat View.f3z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]
2026-05-18 Update README with reference pin map and BOM changes
2026-05-18 Revise wiring and pin map for TFT and encoder
    Updated wiring and pin mapping information for TFT display and rotary encoder module in README.
2026-05-18 Update wiring diagram image in README
2026-05-18 CLEANUP OF FOLDERS
    [ESP32-C3_SUPERMINI_TH.step]
2026-05-19 Add sandpaper and update cost summary in README
    Updated additional costs and added sandpaper to the materials list.
2026-05-25 Update BOM CSV format, add totals; rename image
    Reformatted BOM.csv to use unquoted CSV fields, standardized entries (including an empty link for the 3D printed case), and appended Tax, Shipping, and Total rows. Also renamed images/1776142708711-i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
    [BOM.csv]
2026-05-28 Update CAD models/STEP files; add Google verify
    Regenerate CAD assets and STEP exports: updated Beat View (.f3z, .stl) and MainBody.stl binaries. BackCover.step and MainBody.step timestamps and internal entity references (B_SPLINE surfaces/curves 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
    [BackCover.step, Beat View.f3z, Beat View.stl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]
2026-05-28 Update wiring diagram and pin mapping details
2026-05-28 Update pin map table format in README.md
2026-05-28 Format HMX Xinhai Switches and Rotary Encoder table
2026-05-28 Replace sketch_apr14a with spotify_display_clean
    Remove legacy sketch_apr14a from Firmware and production and add a new spotify_display_clean firmware in both Firmware/ and production/. The new implementation refreshes the UI (new colors, icons, header/footer, progress dot), adds smoother scrolling using a canvas, animated boot and track transitions, improved EQ visualization, volume popup with delayed volume commit, improved WiFi handling, and consolidated button/encoder logic. This change replaces the older BEAT VIEW sketch with a cleaner, feature-rich Spotify display implementation.
    [spotify_display_clean.ino]
2026-05-30 Update parts list and adjust grand total
    Removed the 3D printed case from the parts list and updated the grand total accordingly.
2026-05-30 Remove 3D printed case and update total
    Delete the '3D PRINTED CASE' line from BOM.csv and adjust the final total accordingly. The BOM total was reduced from 24.04 USD to 19.04 USD to reflect the removed 5.00 USD item.
    [BOM.csv]
2026-05-30 Remove unnecessary comments from pin map table
2026-05-30 Fix formatting in README for Reference Pin Map
2026-05-30 Fix formatting in Reference Pin Map section
2026-06-01 BOM: set sandpaper cost to 0 and adjust total
    Update BOM.csv to set SANDPAPER Total Cost (USD) from 3.63 to 0 and adjust the overall total from 19.04 to 16.04 so the BOM totals reflect the price change. No other items were modified.
    [BOM.csv]
2026-06-01 Enhance BOM with links and formatting updates
    Updated the Bill of Materials (BOM) section to include links for each item and corrected formatting.
2026-06-04 Correct Key Switches URL in BOM.csv
    Update the Key Switches entry in BOM.csv to replace the original HMX Xinhai switch URL with the keycaps product URL (previously duplicated/mislinked). No other fields (quantity, price, vendor) were changed.
    [BOM.csv]
